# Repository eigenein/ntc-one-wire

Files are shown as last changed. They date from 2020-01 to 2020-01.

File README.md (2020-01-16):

I've made this device to connect my [NTC thermistor](https://en.wikipedia.org/wiki/Thermistor#NTC) to a [Livolo thermostat](https://www.livolo.eu/c-4632899/livolo-thermostat/) which only works with a built-in [DS18B20 digital thermometer](https://www.maximintegrated.com/en/products/sensors/DS18B20.html).





## Instructions

### [`table.h`](src/table.h)

You need to generate the [`table.h`](src/table.h) for your particular NTC thermistor. It contains an array which maps a measured ADC value to actual temperature. You can do this via the provided [`table.py`](table.py) script.

Measure your NTC resistance at two different temperature points. Then call [`table.py`](table.py) specifying your measurements:

```sh
python table.py \
    --t1 <temperature-1> --r1 <resistance-at-t1> \
    --t2 <temperature-2> --r2 <resistance-at-t2> \
    --rf <fixed-resistor>
```

If your program memory is too small, you can specify `--min-t` and/or `--max-t` parameters. Then the table will be generated in a specified temperature range generating less array entries thus taking less memory.

See [Measuring the temperature with NTCs](http://www.giangrandi.ch/electronics/ntc/ntc.shtml) for more information on how the conversion is implemented.

### Schematic

- `R2` is a fixed resistor with a known resistance. Start with a one that is close to your typical NTC resistance. I recommend to measure actual resistance of the resistor before passing it as `--rf` to improve readings accuracy.
- `C1` aims to filter noise on the NTC wires. It may be tempting to remove it but then you'll sometimes get inadequate readings. You may adjust it though depending on how fast temperature changes in your setup.
- I use `MISO` pin for 1-Wire data line because then I'm able to solder the power and data wires close to each other [on the ICSP header](https://www.arduino.cc/en/reference/SPI).
- I used a self-fusing electrical tape to wrap the entire Arduino board and put it into a flush-mounted box behind the thermostat.

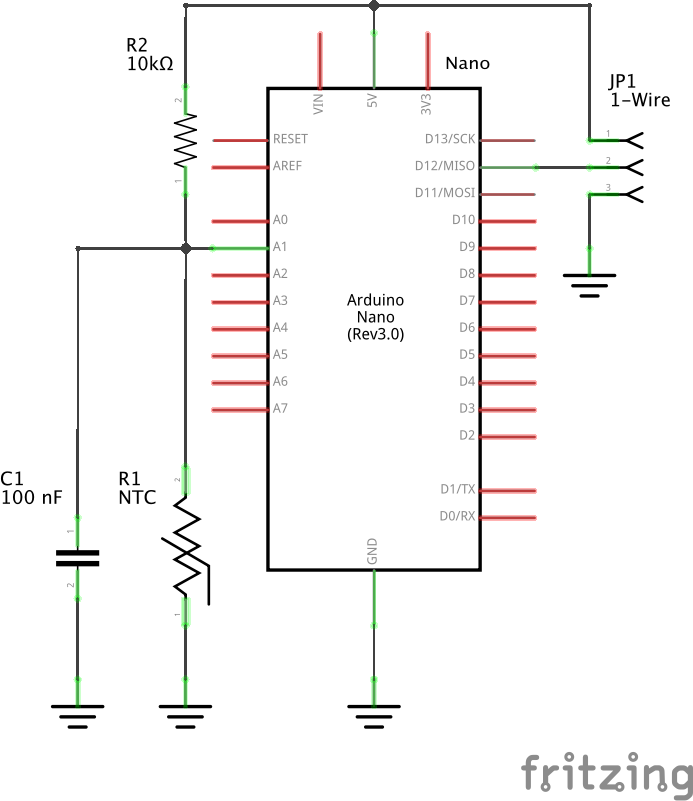
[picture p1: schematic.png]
Schematic


### Note for [Livolo thermostats](https://www.livolo.eu/c-4632899/livolo-thermostat/)

In short, damn them! 😡

1. Livolo's 1-Wire master has non-standard timings and reads only the first 2 bytes of the entire DS18B20's response. You'll need to patch [OneWireHub](https://github.com/orgua/OneWireHub)'s `OneWireHub_config.h` and `DS18B20.cpp` using the included [`livolo.patch`](livolo.patch). See also https://github.com/orgua/OneWireHub/issues/84.
1. (Still checking this point.) Supposingly, one has to solder out the second sensor deep inside the thermostat **even before turning it on for the first time**. If you've already done that, you may try to figure out the calibrated temperature offset that the thermostat has calculated and remembered. Wait ~4 minutes and note the difference between displayed and real ambient temperatures. Then, change `livoloOffset` in the source code to compensate this.

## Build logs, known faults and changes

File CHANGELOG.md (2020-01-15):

## `master`

- Fix: `interval` variable was not used

## `0.1.1b`

- Change: remove exponential smoothing because the capacitor is still needed
- New: add `livoloShift` (see the `README`)
- New: serial debugging
- New: watchdog timer

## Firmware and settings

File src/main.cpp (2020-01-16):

#include <Arduino.h>
#include <avr/wdt.h>

#include <DS18B20.h>

#include "table.h"

// NTC input pin. Another NTC wire goes to the ground.
// This pin should be pulled up by a fixed resistor with a known resistance.
constexpr uint8_t adcPin = A1;

// Temperature measurement interval (approximate).
constexpr unsigned long interval = 1000;

// 1-Wire I/O.
auto hub = OneWireHub(12); // PB4 aka MISO
auto ds18b20 = DS18B20(0x28, 0x92, 0x23, 0xC5, 0x1E, 0x19, 0x01); // Copied from a real sensor: 289223C51E190171.

// Error LED pin.
constexpr uint8_t ledPin = 13;

// Livolo thermostat performs some calibration.
// This is the temperature offset we apply to match the actual temperature.
constexpr float livoloOffset = +3.0f;

void setup() {
    // I've never experienced a freeze on `hub.poll()`, but just in case enabling 8 seconds WDT.
    wdt_disable();
    wdt_enable(WDTO_8S);

    // Note the baud rate if you want to run a serial monitor.
    // I've set the maximum for Arduino Nano to reduce the time spent by `Serial.print()` in `loop()`.
    Serial.begin(2000000);
    while (!Serial);

    pinMode(adcPin, INPUT);

    pinMode(ledPin, OUTPUT);
    digitalWrite(ledPin, LOW);

    // Default temperature according to the datasheet.
    ds18b20.setTemperatureRaw(0x0550);
    hub.attach(ds18b20);
}

float readTemperature(const uint8_t pin) {
    return adcToTemperature(analogRead(pin));
}

void loop() {
    static uint32_t nextMillis = millis();

    wdt_reset();
    hub.poll();

    // Display the error flag. Timeouts are okay.
    const auto error = (uint8_t)hub.getError();
    const auto isError = (error != 0) && (error != 3);
    digitalWrite(13, isError ? HIGH : LOW);
    if (isError) {
        Serial.print("E: ");
        Serial.println(error);
    }

    if (millis() > nextMillis) {
        // Schedule the next measurement.
        nextMillis = millis() + interval;

        const auto reading = readTemperature(adcPin);
        ds18b20.setTemperature(reading + livoloOffset);

        Serial.print(millis());
        Serial.print(" ms | ");
        Serial.print(reading);
        Serial.println(" °C");
        Serial.flush();
    }
}

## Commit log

2019-12-18 Fix: fix bugs and add indication
    [main.cpp]
2019-12-22 Chore: switch to Arduino IDE
2020-01-15 Bunch of fixes - Remove exponential smoothing because the capacitor is still needed - Add `livoloShift` - Add serial debugging - Add watchdog timer
    [main.cpp]
2020-01-15 Fix: `interval` variable was not used
    [main.cpp]
2020-01-16 Chore: add schematic
    [schematic.fzz]
